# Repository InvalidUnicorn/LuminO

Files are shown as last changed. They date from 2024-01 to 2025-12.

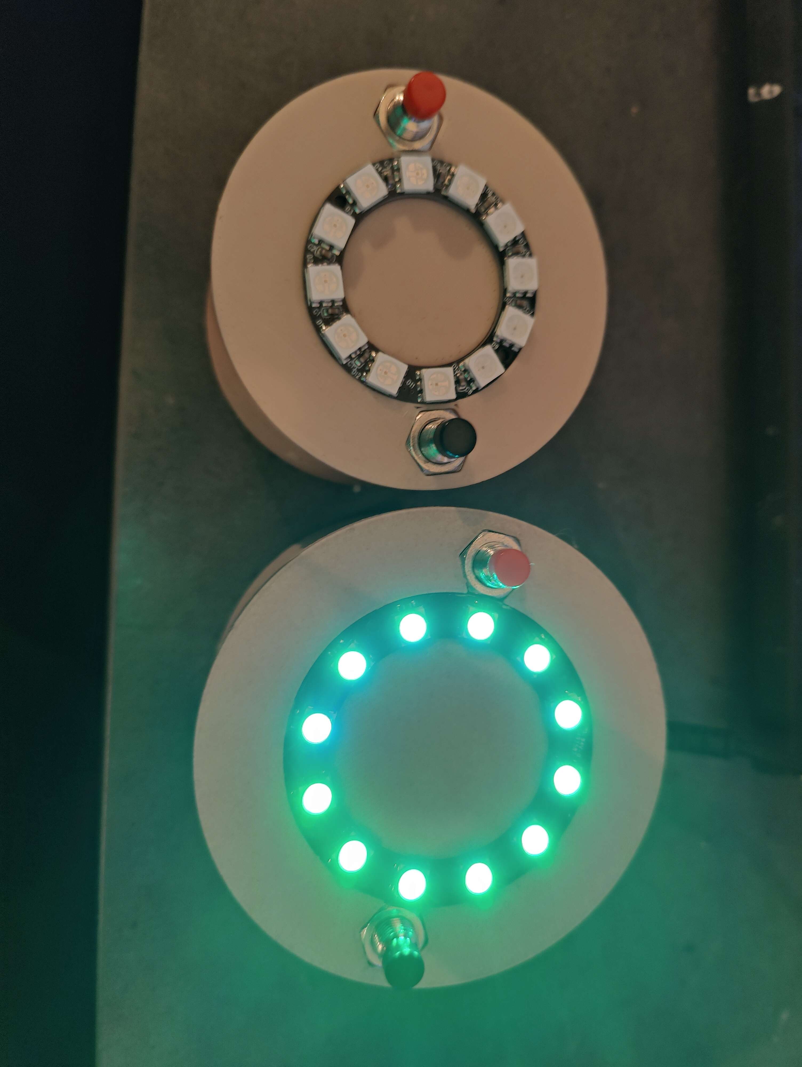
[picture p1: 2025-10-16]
small_and_big_LuminO.jpg

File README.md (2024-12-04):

# LuminO
Winter Projekt des Moduls *Soft Skills und technische Kompetenz* der Carl von Ossietzky Universität Oldenburg.

## 3D Druck Dateien
Es stehen 2 verschiedene Versionen des Gehäuses zur Verfügung.
Eine 30mm und eine 50mm Version. Je nachdem welchen Außendurchmesser der LED Ring hat, muss die ensprechende Datei gedruckt werden.
Die Version für den kleineren Ring ist generell schneller und günstiger druckbar.

## Bauanleitung und Materialliste
Bauanleitung enthält eine bebilderte Schritt-für-Schritt Anleitung für den Zusammenbau des LuminOs.

Um das Projekt umzusetzen müssen einige Materialien besorgt werden.
Das Projekt kann mit oder ohne Akku umgesetzt werden. Entsprechende Teile sind optional.

| Komponente | Menge |
| ---  | --- |
| D1 Mini Battery Shield | 1x (optional) |
| 400mAh Lipo Akku | 1x (optional) |
| Wemos D1 Mini | 1x |
| Mini Momentan Druckknopf | 2x |
| 12 LED Neopixel Ring | 1x |
| Lochrasterplatine (50x26 mm) | 1x |

Die genaue Kapazität des Akkus ist zweitrangig. Er sollte nur nicht viel größer als 30x30 mm sein um in das Gehäuse zu passen.

## Testprogramm
LuminO_TEST enthält einen Arduino Sketch der nach dem Fertigstellen des Projekts auf den D1 Mini geladen werden kann.
Mit hilfe des Sketches können beide Buttons sowie der Led Ring auf richtige funktion geprüft werden.

## Lizenz
Die in diesem Repository enthaltenen Workshopmaterialien werden unter  zur Verfügung gestellt.

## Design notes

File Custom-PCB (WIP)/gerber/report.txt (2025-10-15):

Warnung: Breitenkorrektur eingeschränkt.  Für die aktuellen Designregeln muss sich der Breitenkorrekturwert im Bereich [0,000001 mm; 0,199999 mm] befinden.
Plotted to 'E:\Sparki\Dokumente\LuminO\LuminO-F_Cu.gbr'.
Plotted to 'E:\Sparki\Dokumente\LuminO\LuminO-B_Cu.gbr'.
Plotted to 'E:\Sparki\Dokumente\LuminO\LuminO-F_Paste.gbr'.
Plotted to 'E:\Sparki\Dokumente\LuminO\LuminO-B_Paste.gbr'.
Plotted to 'E:\Sparki\Dokumente\LuminO\LuminO-F_Silkscreen.gbr'.
Plotted to 'E:\Sparki\Dokumente\LuminO\LuminO-B_Silkscreen.gbr'.
Plotted to 'E:\Sparki\Dokumente\LuminO\LuminO-F_Mask.gbr'.
Plotted to 'E:\Sparki\Dokumente\LuminO\LuminO-B_Mask.gbr'.
Plotted to 'E:\Sparki\Dokumente\LuminO\LuminO-Edge_Cuts.gbr'.
Plotted to 'E:\Sparki\Dokumente\LuminO\gerber\LuminO-F_Cu.gbr'.
Plotted to 'E:\Sparki\Dokumente\LuminO\gerber\LuminO-B_Cu.gbr'.
Plotted to 'E:\Sparki\Dokumente\LuminO\gerber\LuminO-F_Paste.gbr'.
Plotted to 'E:\Sparki\Dokumente\LuminO\gerber\LuminO-B_Paste.gbr'.
Plotted to 'E:\Sparki\Dokumente\LuminO\gerber\LuminO-F_Silkscreen.gbr'.
Plotted to 'E:\Sparki\Dokumente\LuminO\gerber\LuminO-B_Silkscreen.gbr'.
Plotted to 'E:\Sparki\Dokumente\LuminO\gerber\LuminO-F_Mask.gbr'.
Plotted to 'E:\Sparki\Dokumente\LuminO\gerber\LuminO-B_Mask.gbr'.
Plotted to 'E:\Sparki\Dokumente\LuminO\gerber\LuminO-Edge_Cuts.gbr'.
Hinweis: Fertig.
Hinweis: Fertig.

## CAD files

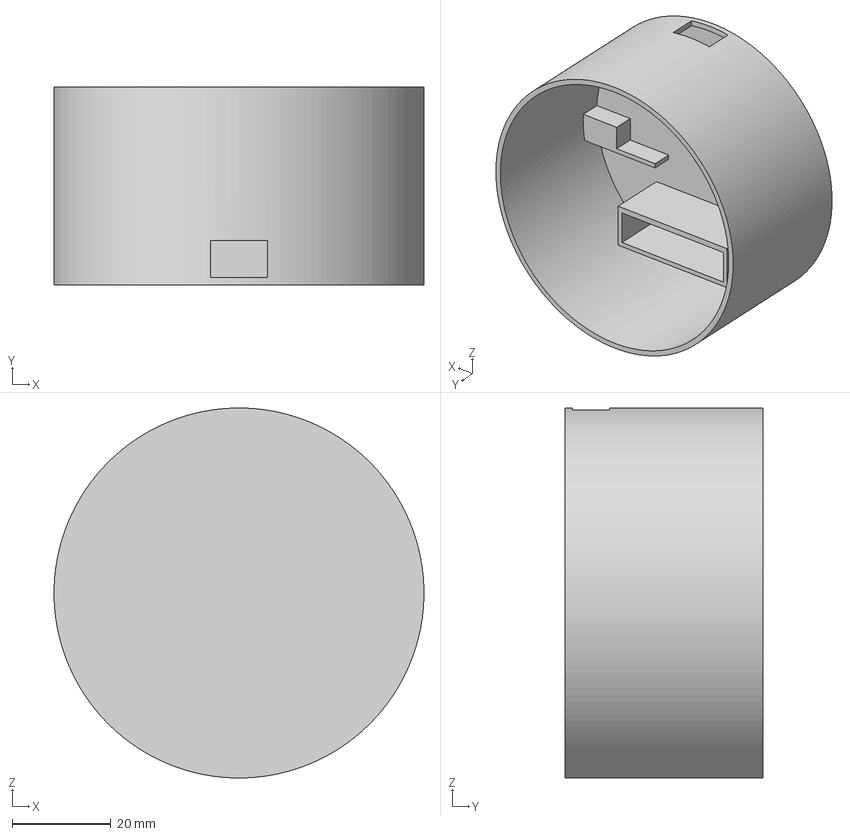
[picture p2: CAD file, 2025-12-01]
3D Models/LuminO_39mm_Base.3mf
74.9 x 40.0 x 74.9 mm

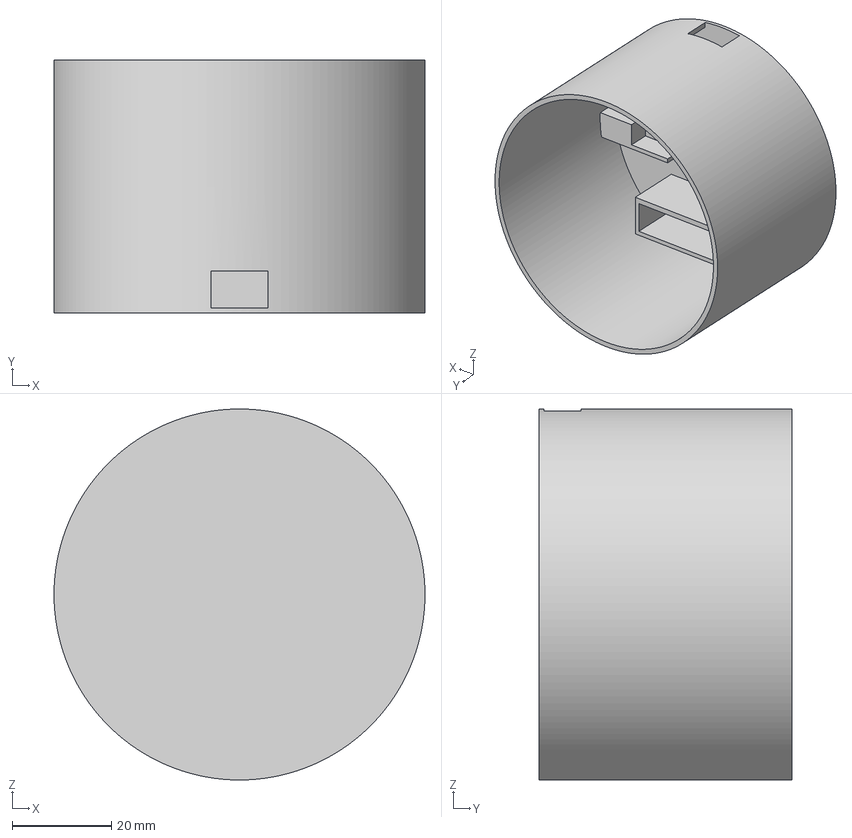
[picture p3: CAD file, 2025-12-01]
3D Models/LuminO Base 30mm_50mm.3mf
74.9 x 51.0 x 74.9 mm

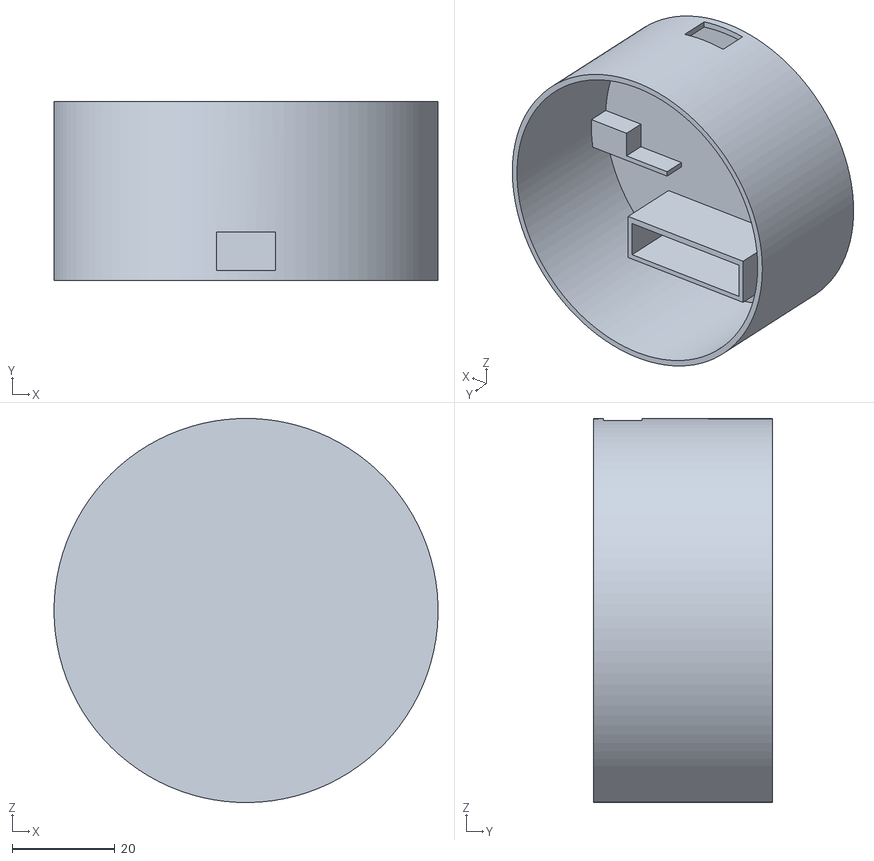
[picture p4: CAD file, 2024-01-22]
3D Models/LuminO Base 50mm.stl
74.9 x 35.0 x 74.9

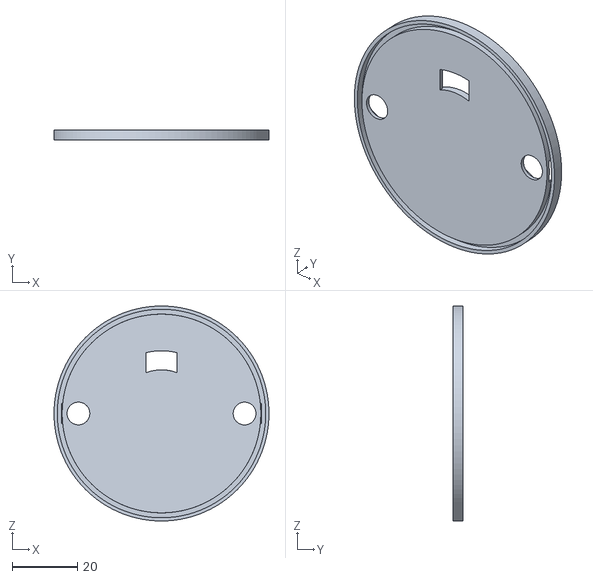
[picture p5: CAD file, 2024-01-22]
3D Models/LuminO Lid 30mm.stl
66.0 x 3.00 x 66.0

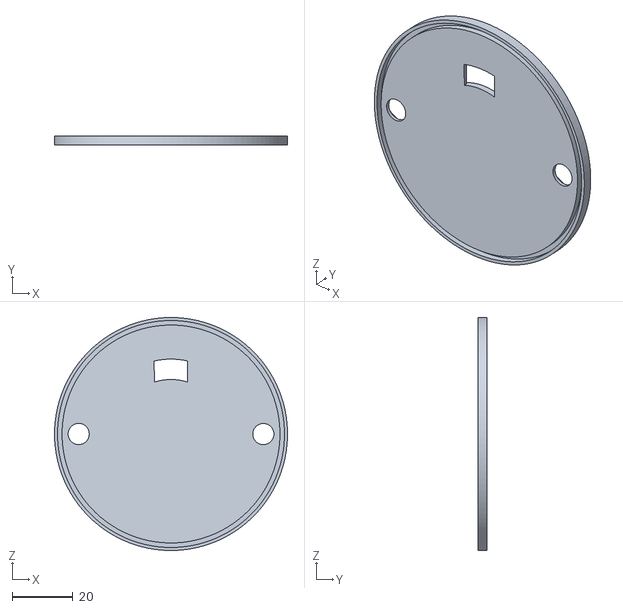
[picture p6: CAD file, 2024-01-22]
3D Models/LuminO Lid 50mm.stl
77.0 x 3.00 x 77.0

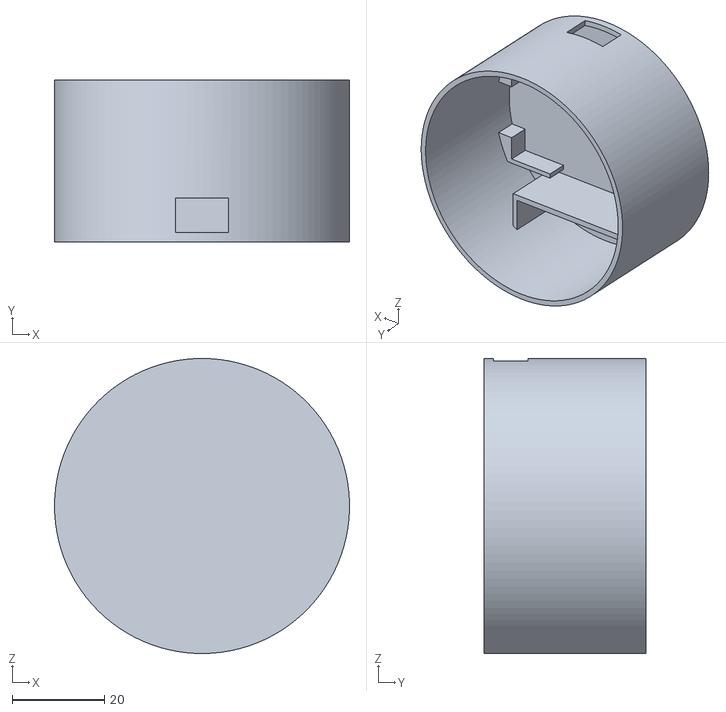
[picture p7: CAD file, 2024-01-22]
3D Models/LuminO Base 30mm.stl
63.9 x 35.0 x 63.9

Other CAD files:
3D Models/LuminO 30 mm 39mm.f3d
3D Models/LuminO 30mm 50 mm.f3d
3D Models/LuminO.f3d

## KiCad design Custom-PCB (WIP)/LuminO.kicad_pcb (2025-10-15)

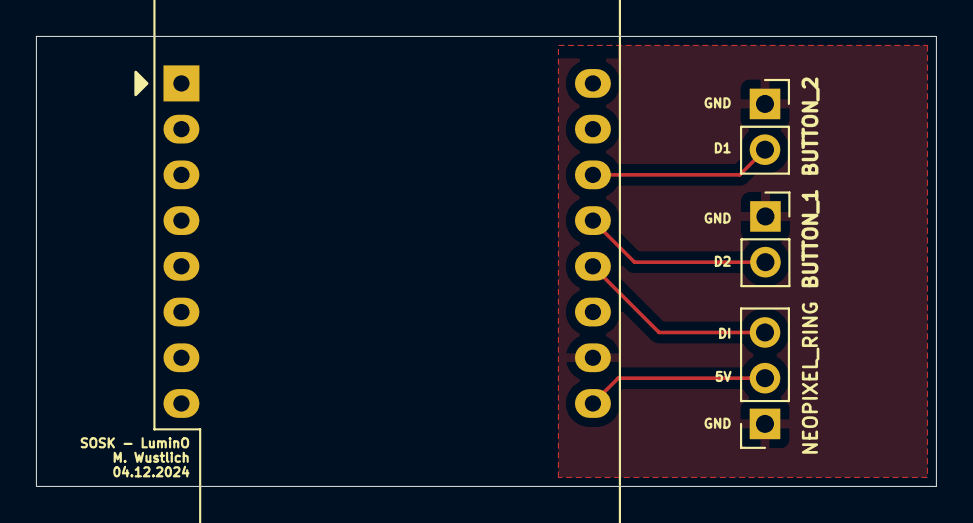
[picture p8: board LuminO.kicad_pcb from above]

Board: 2 copper layers, 50.0 x 25.0 mm, 4 parts (0 on the bottom side), 5 nets.

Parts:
BUTTON_1, BUTTON_2: Conn_01x02_Socket; PinSocket_1x02_P2.54mm_Vertical
NEOPIXEL_RING: Conn_01x03_Socket; PinSocket_1x03_P2.54mm_Vertical
U1: WEMOS_D1_mini; WEMOS_D1_mini_light

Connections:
GND: BUTTON_1.1, BUTTON_2.1, NEOPIXEL_RING.1, U1.10 (GND)
unnamed: NEOPIXEL_RING.2, U1.9 (5V)
unnamed: NEOPIXEL_RING.3, U1.12 (D3)
unnamed: BUTTON_2.2, U1.14 (SCL/D1)
unnamed: BUTTON_1.2, U1.13 (SDA/D2)

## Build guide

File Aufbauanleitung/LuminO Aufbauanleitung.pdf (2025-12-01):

LuminO Aufbauanleitung

Material | Menge
Buchsenleiste (lange Beine) (in der Packung vom Wemos) | 2x
Steckleiste Stifte (in der Packung vom Wemos) | 2x
12 LED NeoPixel Ring | 1x
Lochrasterplatine (19x10 Löcher) | 1x
Taster mit Kabel und Mutter | 2x
Wemos D1 Mini | 1x
D1 Mini Battery Shield | 1x
LiPo Akku 30x35cm (400mAh) | 1x
3D-Druck Deckel | 1x
3D-Druck Gehäuse | 1x
Kabel zum Verlöten | beliebig

Vorwort:
Lies dir die komplette Anleitung einmal durch, bevor du anfängst. Das verhindert Fehler, die du machst, weil du ggf. Informationen überliest. Stelle fragen, wenn etwas unklar ist.

Schritt 1:
Nimm dir die beiden Buchsenleisten mit langen Beinen und das Battery Shield und schiebe die Buchsenleisten von oben durch das Battery Shield und löte sie anschließend fest. Die obere Seite des Battery Shields ist die mit den Komponenten. ACHTUNG: Noch nichts abknipsen.
TIPP: Die Lochplatine kann dir helfen die Buchsen gerade anzulöten.
Stecke dazu die Steckleiste durch die Platine in die Buchsenleiste wie im Bild.

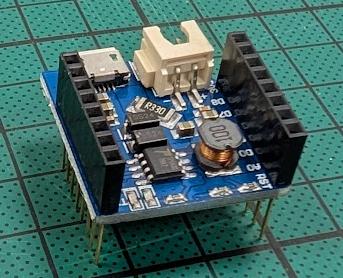
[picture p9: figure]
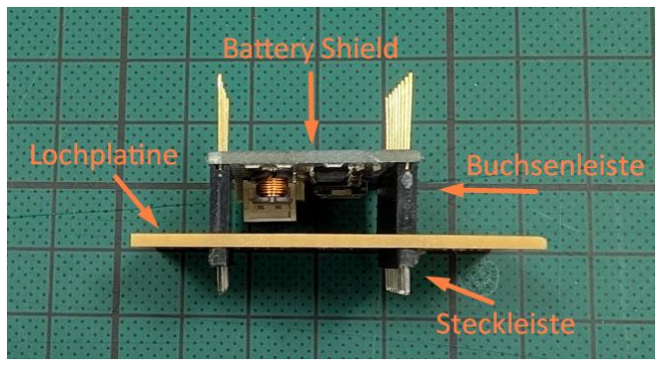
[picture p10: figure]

Schritt 2:
Sobald die Buchsenleisten an allen Stellen verlötet sind, nimm dir die Lochrasterplatine und stecke das Battery Shield mit Hilfe der angelöteten Buchsenleiste von oben durch die Lochrasterplatine. Achte auf die richtige Positionierung des Battery Shields auf der Lochrasterplatine. Am unteren rechten Rand müssen 2 Löcher zur rechten Seite und 1-2 Löcher nach unten frei bleiben! Die untere Seite der Lochrasterplatine ist die mit kupferfarbenen Lötaugen. Löte nun die durchgesteckten Beine der Buchsenleisten an der Lochrasterplatine fest. ACHTUNG: Wenn du den Tipp vorher benutzt hast, baue alles vom Tipp erst wieder auseinander.

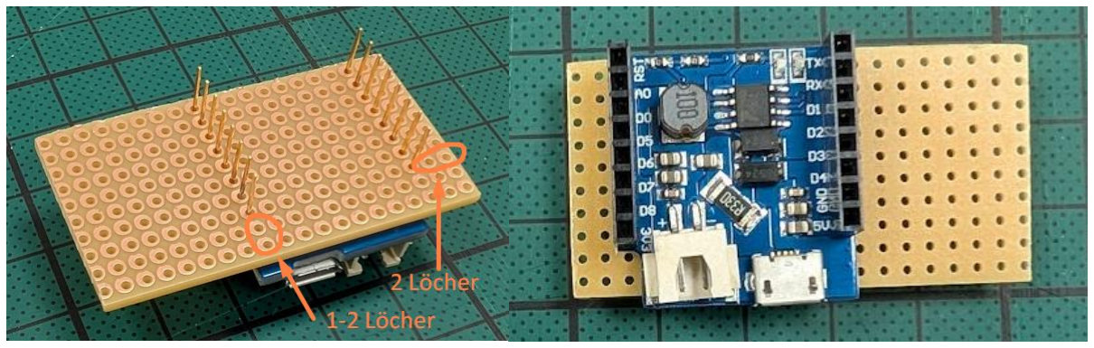
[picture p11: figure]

Schritt 3:
Lege nun das Battery Shield samt Lochrasterplatine zur Seite und nehme den Wemos D1 Mini sowie die Steckleisten. Stecke die kurze Seite der Steckleisten von unten durch den D1 Mini und löte sie oben an allen Stellen fest. Die obere Seite des D1 Mini ist die mit dem silbernen Kühlkörper.

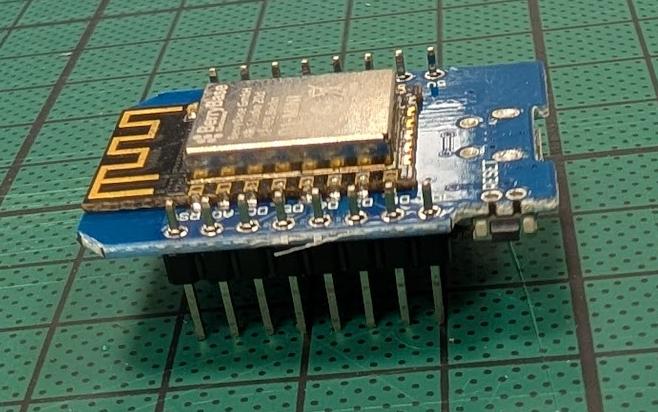
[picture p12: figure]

Schritt 4:
Lege alles zur Seite und nehme dir den 12 LED NeoPixel Ring sowie 3 verschiedenfarbige Kabel z.B. Gelb, Rot und Schwarz. Die Kabel sollten ca. 10cm lang sein und 3 mm abisoliert werden. Im weiteren Verlauf der Anleitung werden wir mit den Beispiel Farben arbeiten. Es macht also Sinn, genau diese zu nehmen. Löte die Kabel nun wie folgt an:
- DI = Gelb
- 5V = Rot
- GND = Schwarz

DO wird freigelassen. Der Anschluss ist für uns nicht von Nutzen. ACHTUNG: Der LED Ring sollte “perfekt” rund sein. Es kann sein, dass produktionsbedingt kleine Teile vom Ring abstehen. Diese musst du vor dem Löten mit einer Pfeile entfernen.

Schritt 5:

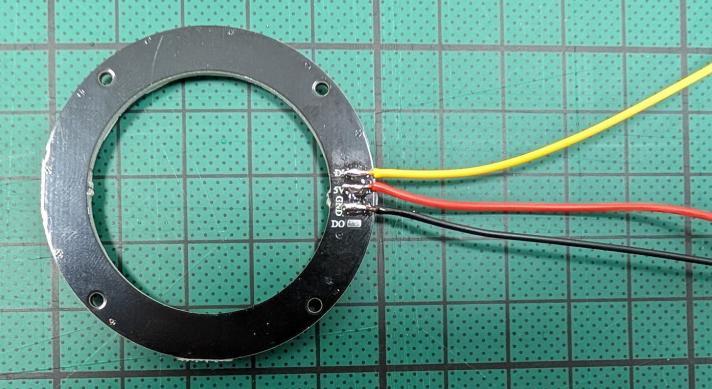
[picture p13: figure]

Nimm dir nun den 3D-Druck Deckel und führe die Kabel von dem LED Ring durch das Loch in der runden Aussparung oben im Deckel. Der Ring sollte fest in der Aussparung sitzen. Eventuell musst du nochmal etwas feilen, wenn der Ring nicht passen sollte. Nimm dir anschließend die beiden Taster mit Kabel und Mutter und schraube die beiden Muttern ab. Die Federringe kannst du zur Seite legen, die brauchen wir nicht. Lege die Muttern in die Aussparung oben im Deckel und schraube die Taster von unten am Deckel fest.

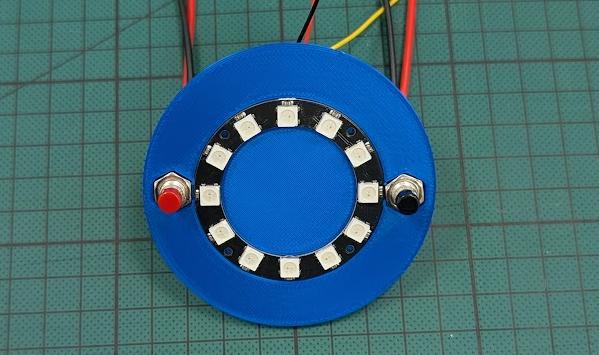
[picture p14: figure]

Schritt 6:
Nimm dir nun die Lochrasterplatine mit dem aufgelötetem Battery Shield. Nun werden alle nötigen Kabel auf die Platine gelötet. Achte darauf, alle Kabel von oben durch die Platine zu schieben. Das Schema ist wie folgt:

Taster 1:
- Rotes Kabel zu D2
- Schwarzes Kabel zu GND
Taster 2:
- Rotes Kabel zu D3
- Schwarzes Kabel zu GND
LED Ring:
- Rotes Kabel zu 5V
- Schwarzes Kabel zu GND
- Gelbes Kabel zu D1

Bei Kabeln, welche nebeneinander liegen, müssen Lötbrücken gemacht werden. Ebenso brauchst du Lötbrücken zwischen Kabel und Pin am Battery Shield. Pass auf, dass du auf der Oberseite keine kleinen Kupferkabel hast, die für Kurzschlüsse sorgen könnten. Solltest du welche finden, schneide sie ab.

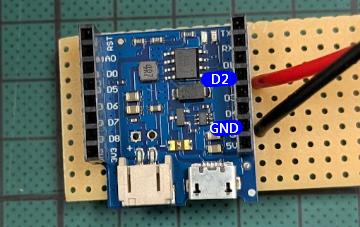
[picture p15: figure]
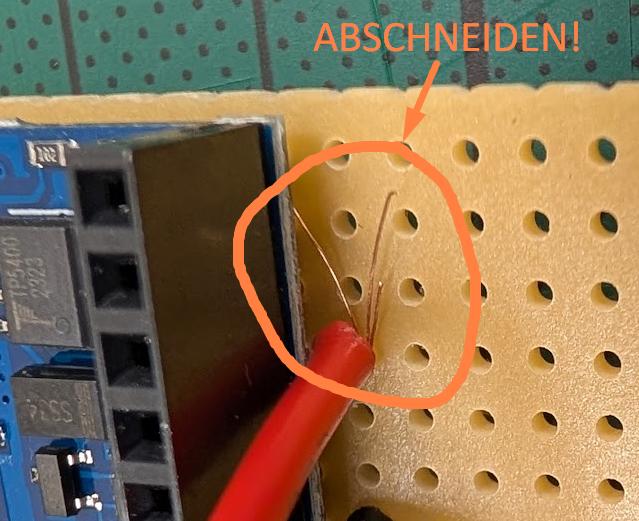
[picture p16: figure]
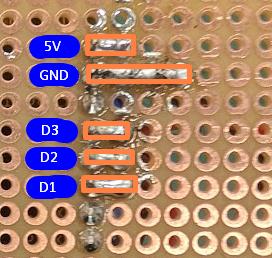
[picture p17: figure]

Schritt 7:
Nimm dir den D1 Mini mit den angelöteten Beinen und stecke ihn auf die Buchsenleiste des Battery Shields. Achte darauf, dass die Pins vom D1 Mini mit denen auf dem Battery Shield übereinstimmen.

Schritt 8:

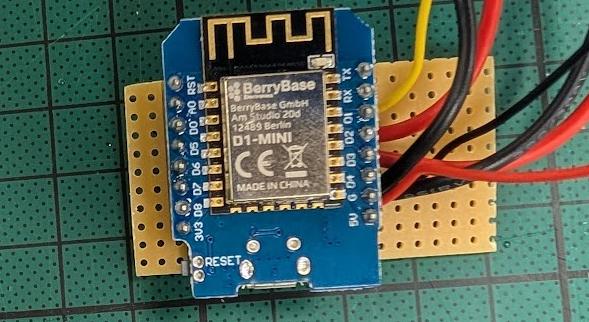
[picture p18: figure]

Glückwunsch. Dein eigener LuminO ist nun fertig gelötet.
Melde dich bei einem Tutor, um dein Projekt prüfen zu lassen, bevor du Strom anschließt. Anschließend kannst du ihn testen.

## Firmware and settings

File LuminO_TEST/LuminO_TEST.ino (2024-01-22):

#include <Adafruit_NeoPixel.h> // Libary for LED-Ring

#define LED_PIN D1 // Make sure this PIN is right!
#define BUTTON_RED_PIN D2 // Make sure this PIN is right!
#define BUTTON_BLACK_PIN D3 // Make sure this PIN is right!
#define STRIPSIZE 12

Adafruit_NeoPixel strip = Adafruit_NeoPixel(STRIPSIZE, LED_PIN, NEO_GRB + NEO_KHZ800);

void setup() {
  
  Serial.begin(9600);
  pinMode(BUTTON_RED_PIN, INPUT_PULLUP); // Initialize Red Button
  pinMode(BUTTON_BLACK_PIN, INPUT_PULLUP); // Initialize Black Button
  strip.begin();
  strip.setBrightness(50);  // Lower brightness and save eyeballs!
  strip.show(); // Initialize all pixels to 'off'
}

void loop() {
  if(!digitalRead(BUTTON_RED_PIN) && !digitalRead(BUTTON_BLACK_PIN)) {
    rainbow(30);
  }
  if(!digitalRead(BUTTON_RED_PIN)) {
    colorFill(255,0,0);
    return;
  }
  if(!digitalRead(BUTTON_BLACK_PIN)) {
    colorFill(255,255,255);
    return;
  }
  colorFill(0,0,0);
  delay(10);
}


void rainbow(uint8_t wait) {
  uint16_t i, j;

  for(j=0; j<256; j++) {
    for(i=0; i<strip.numPixels(); i++) {
      strip.setPixelColor(i, Wheel((i*1+j) & 255));
    }
    strip.show();
    delay(wait);
  }
}

void colorFill(int r, int g, int b) {
  for(int i=0; i < strip.numPixels(); i++) {
      strip.setPixelColor(i, strip.Color(r, g, b));
      strip.show();
  }
}


// Input a value 0 to 255 to get a color value.
// The colours are a transition r - g - b - back to r.
uint32_t Wheel(byte WheelPos) {
  if(WheelPos < 85) {
    return strip.Color(WheelPos * 3, 255 - WheelPos * 3, 0);
  } 
  else if(WheelPos < 170) {
    WheelPos -= 85;
    return strip.Color(255 - WheelPos * 3, 0, WheelPos * 3);
  } 
  else {
    WheelPos -= 170;
    return strip.Color(0, WheelPos * 3, 255 - WheelPos * 3);
  }
}

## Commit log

2024-01-22 initial file upload
    2 versions of 3D models.
    Print them depending on your LED ring size.
    [LuminO Base 30mm.stl, LuminO Base 50mm.stl, LuminO Lid 30mm.stl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]
2025-10-15 Added Files for Custom PCB
    Added all Files of KI-CAD Project
    [LuminO-B_Cu.gbr, LuminO-B_Mask.gbr, LuminO-B_Paste.gbr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]
2025-11-19 Added Fusion 360 Project
    [LuminO.f3d]
2025-11-30 Rechtschreibung und Imperativ korrigiert
2025-11-30 Tabelle korrigiert und ˜*.docx-Beabeitungssperre entfernt
2025-12-01 Hinzufügen von neuen Höhen
    Hinzufügen von neuen Größen für die 30 mm Option, damit die neuen Akkus in das Gehäuse passen.
    [LuminO 30 mm 39mm.f3d, LuminO 30mm 50 mm.f3d, LuminO Base 30mm_50mm.3mf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]
2025-12-01 Update Anleitung
    In der Materialliste steht jetzt das die Leisten in der Packung vom Wemos sind.

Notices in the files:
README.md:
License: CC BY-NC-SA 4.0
